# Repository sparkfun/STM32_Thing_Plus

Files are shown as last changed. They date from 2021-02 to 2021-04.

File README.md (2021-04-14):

SparkFun STM32 Thing Plus
========================================

SparkFun STM32 Thing Plus

[*SparkFun STM32 Thing Plus (17712)*](https://www.sparkfun.com/products/17712)

What incorporates a high-performance Arm® Cortex®-M4 32-bit RISC core, a full set of DSP instructions, memory protection unit (MPU), high-speed embedded memories, up to 4 Kbytes of backup SRAM, and an extensive range of enhanced I/Os and peripherals? The new [SparkFun STM32 Thing Plus](https://www.sparkfun.com/products/17712) has all this and more in the popular, Feather-compatible Thing Plus form factor. 

Repository Contents
-------------------

* **/Hardware** - Eagle design files (.brd, .sch)
* **/Production** - Production panel files (.brd)

Documentation
--------------
* **[Hookup Guide](https://learn.sparkfun.com/tutorials/stm32-thing-plus-hookup-guide)** - Basic hookup guide for the STM32 Thing Plus.
* **[SparkFun Graphical Datasheets](https://github.com/sparkfun/Graphical_Datasheets)** -Graphical Datasheets for various SparkFun products.

License Information
-------------------

This product is _**open source**_! 

Please review the LICENSE.md file for license information. 

If you have any questions or concerns on licensing, please contact technical support on our [SparkFun forums](https://forum.sparkfun.com/viewforum.php?f=152).

Distributed as-is; no warranty is given.

- Your friends at SparkFun.

_<COLLABORATION CREDIT>_

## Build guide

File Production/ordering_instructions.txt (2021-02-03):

panel size, 201x124mm
PCB thickness, 1.6mm
number of layers, 2
soldermask color, Red
silkscreen color, White
oz copper, 1oz
finish, HASL lead free
stencils, top+bottom
pcs per panel, 15
min trace width, 0.2000mm / 0.0079in
min drill size, 0.3048mm / 0.0120in

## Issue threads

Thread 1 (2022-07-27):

STM32F405 Express, PCB errors about SD card detection

dombru54, 2022-07-27:
Hello,

1) With your SparkFunThingPlus-STM32F405 card, the PB12 pin (cardDetect) is not connected to reader card pin 10.
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

2) There is a short circuit with the card reader double pin 10
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

Error in the card reader manufacturer's datasheet and red correction
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

Erase thermal-break, pin 10 will no longer be grounded
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

Thanks to make a revision of this board

dombru54, 2022-07-27:
Sorry, error tittle, it's ThingPlus, not Express

Thanks to modify tittle

dombru54, 2022-07-27:
Sorry,
The new schema corrected
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

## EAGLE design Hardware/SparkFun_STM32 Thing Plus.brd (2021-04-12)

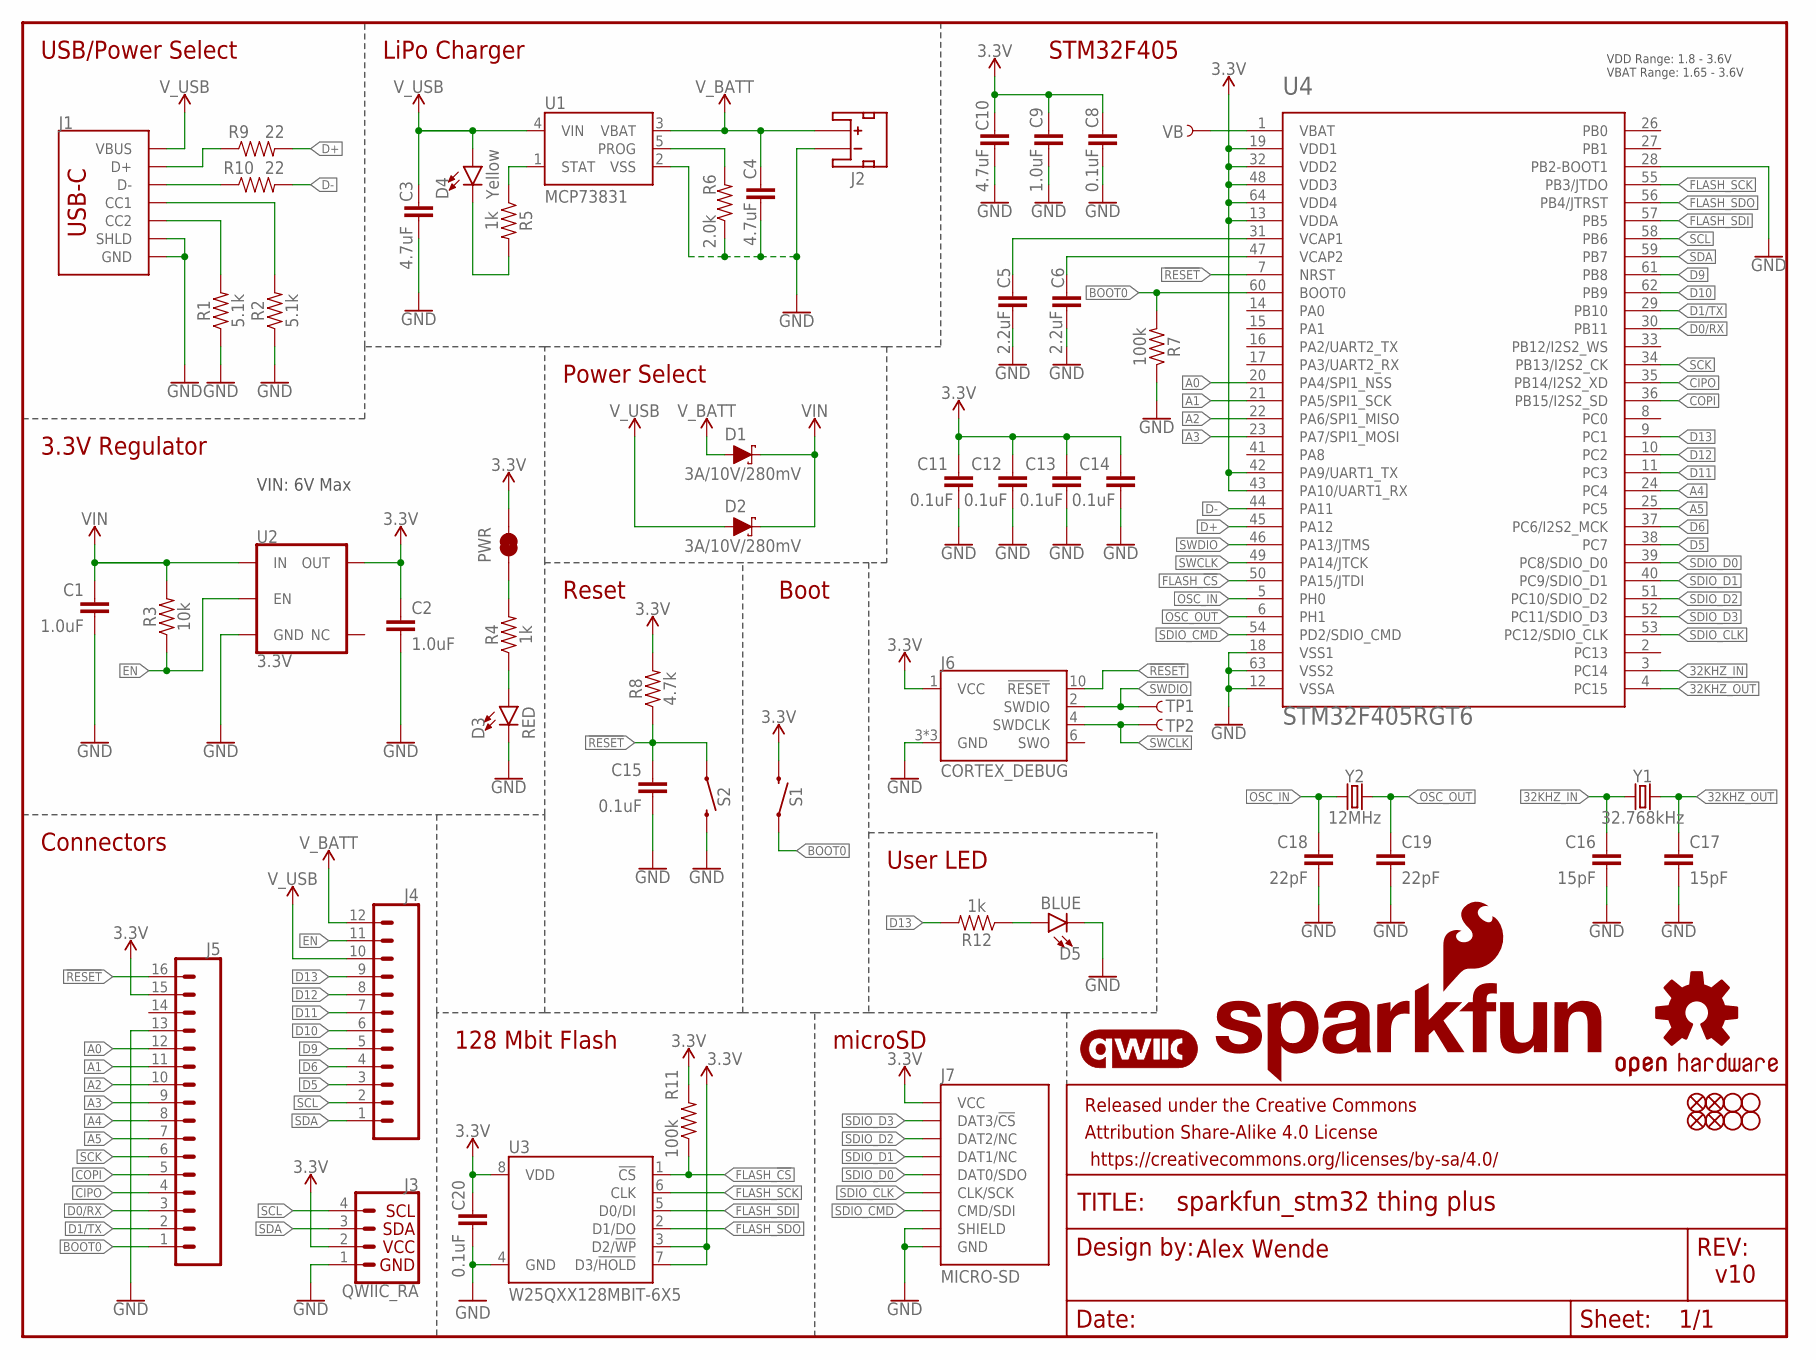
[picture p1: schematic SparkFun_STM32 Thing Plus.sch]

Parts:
C1, C2, C9: 1.0uF; 0402-TIGHT
C3, C4, C10: 4.7uF; 0402-TIGHT
C5, C6: 2.2uF; 0402-TIGHT
C8, C11, C12, C13, C14, C15, C20: 0.1uF; 0402-TIGHT
C16, C17: 15pF; 0402-TIGHT
C18, C19: 22pF; 0402-TIGHT
D1, D2: 3A/10V/280mV; SOD-323
D3: RED; LED-0603
D4: Yellow; LED-0603
D5: BLUE; LED-0603
FD1, FD2, FD3, FD4: FIDUCIALUFIDUCIAL; FIDUCIAL-MICRO
FRAME1: FRAME-LETTER; CREATIVE_COMMONS
H1, H2, H3, H4: STAND-OFFTIGHT; STAND-OFF-TIGHT
J1: USB_C_2-LAYER_PADS; USB-C-16P-2LAYER-PADS
J2: JST_2MM_MALE; JST-2-SMD
J3: QWIIC_RA; JST04_1MM_RA
J4: CONN_12SM_SQ_NO_SILK; 1X12_SM_SQ_NOSILK
J5: CONN_161X16_SM_SQ_NOSILK; 1X16_SM_SQ_NOSILK
J6: CORTEX_DEBUG; 2X5-PTH-1.27MM-NO_SILK
J7: MICRO-SD; MICRO-SD-SOCKET
LOGO1: QWIIC_LOGO_5MM; QWIIC_5MM
LOGO2: SFE_LOGO_NAME_FLAME.1_INCH; SFE_LOGO_NAME_FLAME_.1
LOGO3: OSHW-LOGOS; OSHW-LOGO-S
PWR: JUMPER-SMT_2_NC_TRACE_NO-SILK; SMT-JUMPER_2_NC_TRACE_NO-SILK
R1, R2: 5.1k; 0603
R3: 10k; 0603
R4, R5, R12: 1k; 0402-TIGHT
R6: 2.0k; 0603
R7, R11: 100k; 0402-TIGHT
R8: 4.7k; 0603
R9, R10: 22; 0603
S1, S2: MOMENTARY-SWITCH-SPST-SMD-4.6X2.8MM; TACTILE_SWITCH_SMD_4.6X2.8MM
TP1, TP2: TEST-POINT3; PAD.03X.03
U1: MCP73831; SOT23-5
U2: 3.3V; SOT23-5
U3: W25QXX128MBIT-6X5; WSON-8-6X5
U4: STM32F405RGT6; TQFP64
VB: TEST-POINT3; PAD.03X.03
Y1: 32.768kHz; CRYSTAL-SMD-3.2X1.5MM
Y2: 12MHz; CRYSTAL-SMD-5X3.2-4PAD

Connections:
3.3V: C2.1, C8.1, C9.1, C10.1, C11.1, C12.1, C13.1, C14.1, C20.1, J3.2, J5.15, J6.1 (VCC), J7.VCC, PWR.2, R8.2, R11.2, S1.3 (2), S1.4 (2), U2.5 (OUT), U3.3 (D2/!WP!), U3.7 (D3/!HOLD!), U3.8 (VDD), U4.13 (VDDA), U4.19 (VDD1), U4.32 (VDD2), U4.42 (PA9/UART1_TX), U4.43 (PA10/UART1_RX), U4.48 (VDD3), U4.64 (VDD4)
32KHZ_IN: C16.1, U4.3 (PC14), Y1.P$1 (1)
32KHZ_OUT: C17.1, U4.4 (PC15), Y1.P$2 (2)
!RESET: C15.1, J5.16, J6.10 (!RESET), R8.1, S2.1, S2.2 (1), U4.7 (NRST)
A0: J5.12, U4.20 (PA4/SPI1_NSS)
A1: J5.11, U4.21 (PA5/SPI1_SCK)
A2: J5.10, U4.22 (PA6/SPI1_MISO)
A3: J5.9, U4.23 (PA7/SPI1_MOSI)
A4: J5.8, U4.24 (PC4)
A5: J5.7, U4.25 (PC5)
BOOT0: J5.1, R7.2, S1.1, S1.2 (1), U4.60 (BOOT0)
CIPO: J5.4, U4.35 (PB14/I2S2_XD)
COPI: J5.5, U4.36 (PB15/I2S2_SD)
D0/RX: J5.3, U4.30 (PB11)
D1/TX: J5.2, U4.29 (PB10)
D5: J4.3, U4.38 (PC7)
D6: J4.4, U4.37 (PC6/I2S2_MCK)
D9: J4.5, U4.61 (PB8)
D10: J4.6, U4.62 (PB9)
D11: J4.7, U4.11 (PC3)
D12: J4.8, U4.10 (PC2)
D13: J4.9, R12.2, U4.9 (PC1)
D+: R9.2, U4.45 (PA12)
D-: R10.2, U4.44 (PA11)
EN: J4.11, R3.1, U2.3 (EN)
FLASH_!CS: R11.1, U3.1 (!CS!), U4.50 (PA15/JTDI)
FLASH_SCK: U3.6 (CLK), U4.55 (PB3/JTDO)
FLASH_SDI: U3.5 (D0/DI), U4.57 (PB5)
FLASH_SDO: U3.2 (D1/DO), U4.56 (PB4/JTRST)
GND: C1.2, C2.2, C3.2, C4.2, C5.2, C6.2, C8.2, C9.2, C10.2, C11.2, C12.2, C13.2, C14.2, C15.2, C16.2, C17.2, C18.2, C19.2, C20.2, D3.C, D5.C, J1.GND, J1.GND2 (GND), J1.SHLD1 (SHLD), J1.SHLD2 (SHLD), J1.SHLD3 (SHLD), J1.SHLD4 (SHLD), J2.1 (-), J3.1, J5.13, J6.3 (GND), J6.5 (GND), J6.9 (GND), J7.CD1 (SHIELD), J7.GND, J7.GND1 (GND), J7.GND3 (GND), R1.1, R2.1, R6.1, R7.1, S2.3 (2), S2.4 (2), U1.2 (VSS), U2.2 (GND), U3.4 (GND), U4.12 (VSSA), U4.18 (VSS1), U4.28 (PB2-BOOT1), U4.63 (VSS2)
unnamed: D5.A, R12.1
unnamed: PWR.1, R4.2
unnamed: J1.A6 (D+), J1.B6 (D+), R9.1
unnamed: J1.A7 (D-), J1.B7 (D-), R10.1
unnamed: D3.A, R4.1
unnamed: R6.2, U1.5 (PROG)
unnamed: J1.A5 (CC1), R2.2
unnamed: J1.B5 (CC2), R1.2
unnamed: D4.C, R5.2
unnamed: R5.1, U1.1 (STAT)
unnamed: C5.1, U4.31 (VCAP1)
unnamed: C6.1, U4.47 (VCAP2)
OSC_IN: C18.1, U4.5 (PH0), Y2.1
OSC_OUT: C19.1, U4.6 (PH1), Y2.3 (2)
SCK: J5.6, U4.34 (PB13/I2S2_CK)
SCL: J3.4, J4.2, U4.58 (PB6)
SDA: J3.3, J4.1, U4.59 (PB7)
SDIO_CLK: J7.SCLK (CLK/SCK), U4.53 (PC12/SDIO_CLK)
SDIO_CMD: J7.DI/CMD (CMD/SDI), U4.54 (PD2/SDIO_CMD)
SDIO_D0: J7.DO/DAT0 (DAT0/SDO), U4.39 (PC8/SDIO_D0)
SDIO_D1: J7.DAT1 (DAT1/NC), U4.40 (PC9/SDIO_D1)
SDIO_D2: J7.DAT2 (DAT2/NC), U4.51 (PC10/SDIO_D2)
SDIO_D3: J7.CS/DAT3 (DAT3/!CS!), U4.52 (PC11/SDIO_D3)
SWCLK: J6.4 (SWDCLK), TP2.P$1, U4.49 (PA14/JTCK)
SWDIO: J6.2 (SWDIO), TP1.P$1, U4.46 (PA13/JTMS)
VB: U4.1 (VBAT), VB.P$1
VIN: C1.1, D1.C, D2.C, R3.2, U2.1 (IN)
V_BATT: C4.1, D1.A, J2.2 (+), J4.12, U1.3 (VBAT)
V_USB: C3.1, D2.A, D4.A, J1.VBUS1 (VBUS), J1.VBUS2 (VBUS), J4.10, U1.4 (VIN)

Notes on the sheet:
v10
Alex Wende
3.3V Regulator
VIN: 6V Max
LiPo Charger
USB/Power Select
Power Select
Connectors
microSD
128 Mbit Flash
Reset
Boot
User LED
VDD Range: 1.8 - 3.6V VBAT Range: 1.65 - 3.6V
STM32F405

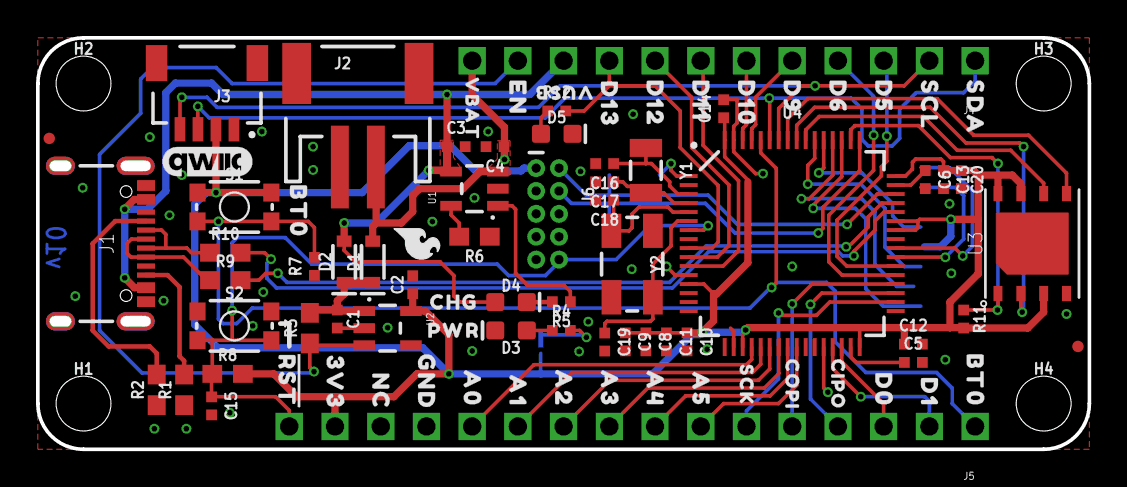
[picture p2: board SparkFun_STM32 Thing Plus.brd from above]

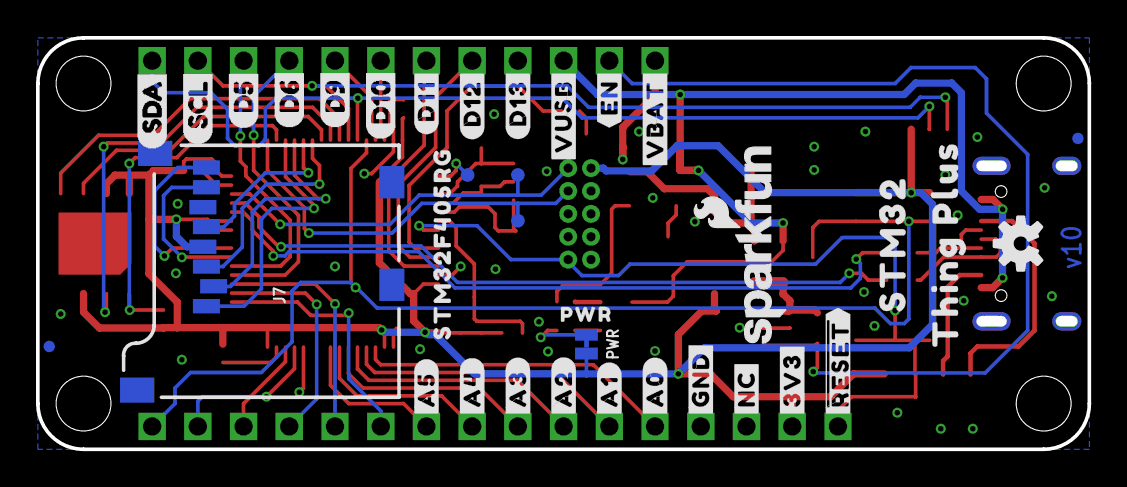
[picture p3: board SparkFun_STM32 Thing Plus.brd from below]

Board: 2 copper layers, 58.4 x 22.9 mm, 125 parts (35 on the bottom side), 59 nets.

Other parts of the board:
U$1: D53
U$2: #RST#0
U$3, U$49: BT00
U$4: D130
U$5, U$58: PWR0
U$6: CHG0
U$7: ##RESET##0
U$8: #3V3#0
U$9: #NC#0
U$10: #GND#0
U$11: #A0#0
U$12: #A1#0
U$13: #A2#0
U$14: #A3#0
U$15: #A4#0
U$16: #A5#0
U$23: D62
U$24: D91
U$25, U$55: D100
U$26: SCL4
U$27: SDA5
U$29: #D11#0
U$30: #D12#0
U$31: #D13#0
U$32: #VUSB#0
U$33: #EN#0
U$34: #VBAT#0
U$35: 3V30
U$36: NC0
U$37: GND0
U$38: A00
U$39: A10
U$40: A20
U$41: A30
U$42: A40
U$43: A50
U$44: SCK0
U$45: COPI0
U$46: CIPO0
U$47: D00
U$48: D10
U$50: VBAT_0
U$51: EN_0
U$52: D50
U$53: D60
U$54: D90
U$56: D110
U$57: D120
U$59: SCL_0
U$60: SDA_0
U$61: VUSB0
U$62: STM320
U$63: THING_PLUS0
U$64: STM32F405RG0
U$65: SFE_LOGO_FLAME_.1

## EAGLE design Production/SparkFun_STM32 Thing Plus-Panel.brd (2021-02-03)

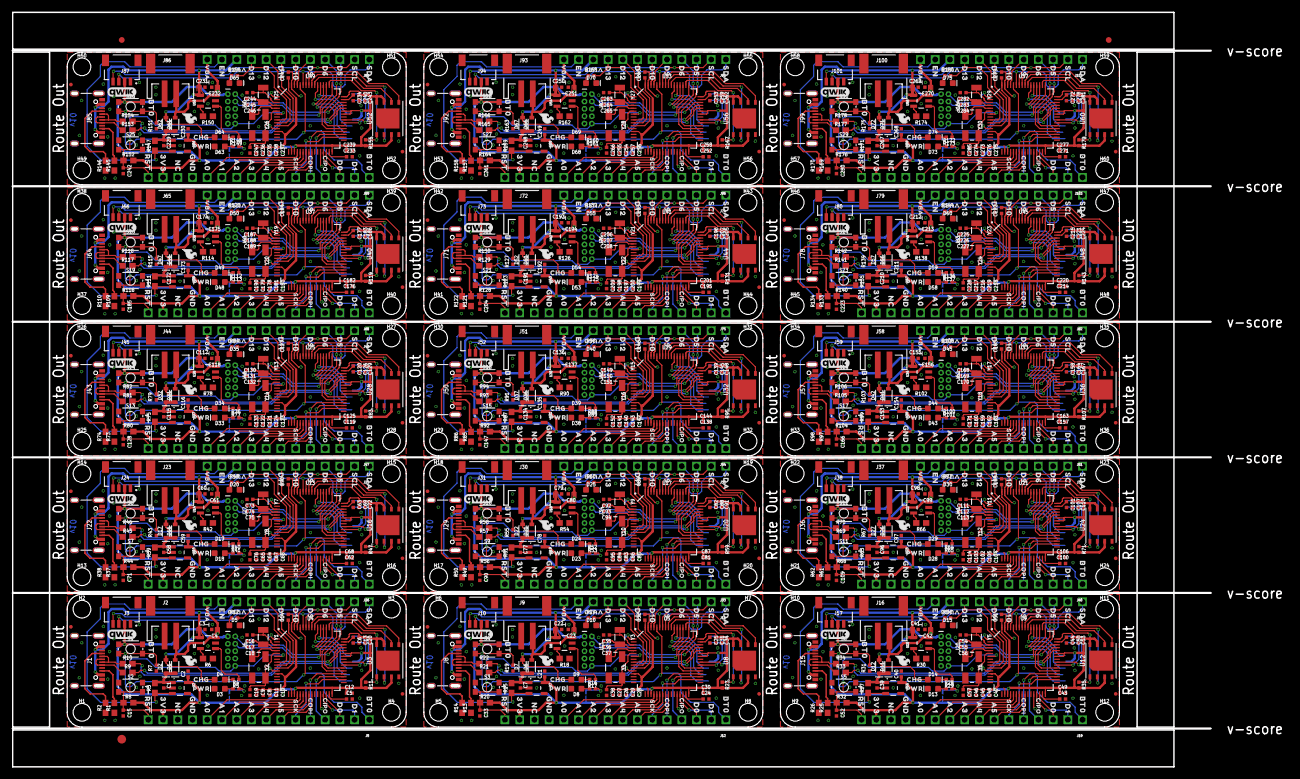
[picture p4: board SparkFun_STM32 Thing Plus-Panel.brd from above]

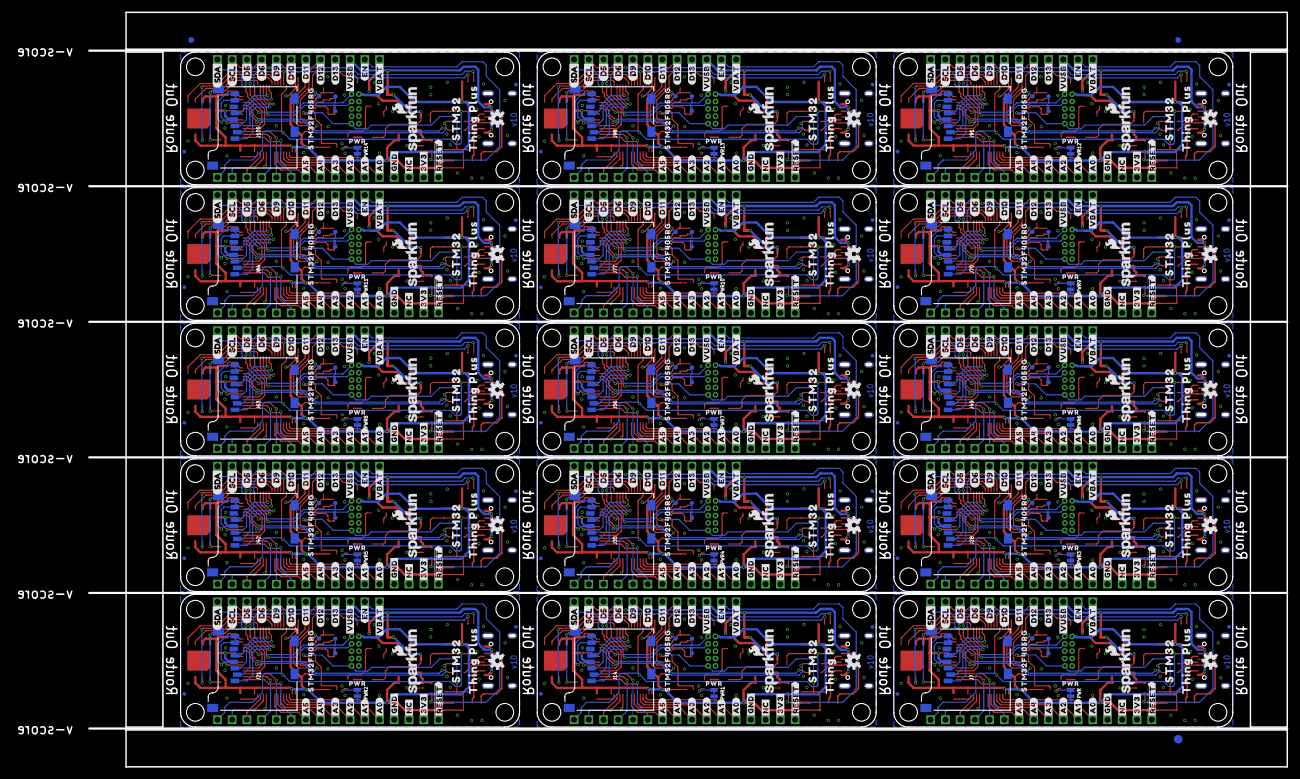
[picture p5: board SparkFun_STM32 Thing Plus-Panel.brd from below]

Board: 2 copper layers, 206.5 x 130.0 mm, 1866 parts (528 on the bottom side), 885 nets.

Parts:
C1, C2, C7, C9, C21, C27, C39, C40, C46, C58, C59, C65, C77, C78, C84, C96, C97, C103, C115, C116, C122, C134, C135, C141, C153, C154, C160, C172, C173, C179, C191, C192, C198, C210, C211, C217, C229, C230, C236, C248, C249, C255, C267, C268, C274: 1.0uF; 0402-TIGHT
C3, C4, C10, C22, C23, C28, C41, C42, C47, C60, C61, C66, C79, C80, C85, C98, C99, C104, C117, C118, C123, C136, C137, C142, C155, C156, C161, C174, C175, C180, C193, C194, C199, C212, C213, C218, C231, C232, C237, C250, C251, C256, C269, C270, C275: 4.7uF; 0402-TIGHT
C5, C6, C24, C25, C43, C44, C62, C63, C81, C82, C100, C101, C119, C120, C138, C139, C157, C158, C176, C177, C195, C196, C214, C215, C233, C234, C252, C253, C271, C272: 2.2uF; 0402-TIGHT
C8, C11, C12, C13, C14, C15, C20, C26, C29, C30, C31, C32, C33, C34, C45, C48, C49, C50, C51, C52, C53, C64, C67, C68, C69, C70, C71, C72, C83, C86, C87, C88, C89, C90, C91, C102, C105, C106, C107, C108, C109, C110, C121, C124, C125, C126, C127, C128, C129, C140, C143, C144, C145, C146, C147, C148, C159, C162, C163, C164, C165, C166, C167, C178, C181, C182, C183, C184, C185, C186, C197, C200, C201, C202, C203, C204, C205, C216, C219, C220, C221, C222, C223, C224, C235, C238, C239, C240, C241, C242, C243, C254, C257, C258, C259, C260, C261, C262, C273, C276, C277, C278, C279, C280, C281: 0.1uF; 0402-TIGHT
C16, C17, C35, C36, C54, C55, C73, C74, C92, C93, C111, C112, C130, C131, C149, C150, C168, C169, C187, C188, C206, C207, C225, C226, C244, C245, C263, C264, C282, C283: 15pF; 0402-TIGHT
C18, C19, C37, C38, C56, C57, C75, C76, C94, C95, C113, C114, C132, C133, C151, C152, C170, C171, C189, C190, C208, C209, C227, C228, C246, C247, C265, C266, C284, C285: 22pF; 0402-TIGHT
D1, D2, D6, D7, D11, D12, D16, D17, D21, D22, D26, D27, D31, D32, D36, D37, D41, D42, D46, D47, D51, D52, D56, D57, D61, D62, D66, D67, D71, D72: 3A/10V/280mV; SOD-323
D3, D8, D13, D18, D23, D28, D33, D38, D43, D48, D53, D58, D63, D68, D73: RED; LED-0603
D4, D9, D14, D19, D24, D29, D34, D39, D44, D49, D54, D59, D64, D69, D74: Yellow; LED-0603
D5, D10, D15, D20, D25, D30, D35, D40, D45, D50, D55, D60, D65, D70, D75: BLUE; LED-0603
E$1, E$2, E$3, E$4: FIDUCIAL-1X2
E$5, E$6: FIDUCIAL-1.5X3
FD1, FD2, FD3, FD4, FD5, FD6, FD7, FD8, FD9, FD10, FD11, FD12, FD13, FD14, FD15, FD16, FD17, FD18, FD19, FD20, FD21, FD22, FD23, FD24, FD25, FD26, FD27, FD28, FD29, FD30, FD31, FD32, FD33, FD34, FD35, FD36, FD37, FD38, FD39, FD40, FD41, FD42, FD43, FD44, FD45, FD46, FD47, FD48, FD49, FD50, FD51, FD52, FD53, FD54, FD55, FD56, FD57, FD58, FD59, FD60: FIDUCIALUFIDUCIAL; FIDUCIAL-MICRO
H1, H2, H3, H4, H5, H6, H7, H8, H9, H10, H11, H12, H13, H14, H15, H16, H17, H18, H19, H20, H21, H22, H23, H24, H25, H26, H27, H28, H29, H30, H31, H32, H33, H34, H35, H36, H37, H38, H39, H40, H41, H42, H43, H44, H45, H46, H47, H48, H49, H50, H51, H52, H53, H54, H55, H56, H57, H58, H59, H60: STAND-OFFTIGHT; STAND-OFF-TIGHT
J1, J8, J15, J22, J29, J36, J43, J50, J57, J64, J71, J78, J85, J92, J99: USB-C-16P-2LAYER-PADS
J2, J9, J16, J23, J30, J37, J44, J51, J58, J65, J72, J79, J86, J93, J100: JST-2-SMD
J3, J10, J17, J24, J31, J38, J45, J52, J59, J66, J73, J80, J87, J94, J101: QWIIC_RA; JST04_1MM_RA
J4, J11, J18, J25, J32, J39, J46, J53, J60, J67, J74, J81, J88, J95, J102: 1X12_SM_SQ_NOSILK
J5, J12, J19, J26, J33, J40, J47, J54, J61, J68, J75, J82, J89, J96, J103: 1X16_SM_SQ_NOSILK
J6, J13, J20, J27, J34, J41, J48, J55, J62, J69, J76, J83, J90, J97, J104: CORTEX_DEBUG; 2X5-PTH-1.27MM-NO_SILK
J7, J14, J21, J28, J35, J42, J49, J56, J63, J70, J77, J84, J91, J98, J105: MICRO-SD; MICRO-SD-SOCKET
LOGO1, LOGO4, LOGO7, LOGO10, LOGO13, LOGO16, LOGO19, LOGO22, LOGO25, LOGO28, LOGO31, LOGO34, LOGO37, LOGO40, LOGO43: QWIIC_LOGO_5MM; QWIIC_5MM
LOGO2, LOGO5, LOGO8, LOGO11, LOGO14, LOGO17, LOGO20, LOGO23, LOGO26, LOGO29, LOGO32, LOGO35, LOGO38, LOGO41, LOGO44: SFE_LOGO_NAME_FLAME.1_INCH; SFE_LOGO_NAME_FLAME_.1
LOGO3, LOGO6, LOGO9, LOGO12, LOGO15, LOGO18, LOGO21, LOGO24, LOGO27, LOGO30, LOGO33, LOGO36, LOGO39, LOGO42, LOGO45: OSHW-LOGOS; OSHW-LOGO-S
PWR, PWR1, PWR2, PWR3, PWR4, PWR5, PWR6, PWR7, PWR8, PWR9, PWR10, PWR11, PWR12, PWR13, PWR14: SMT-JUMPER_2_NC_TRACE_NO-SILK
R1, R2, R13, R14, R25, R26, R37, R38, R49, R50, R61, R62, R73, R74, R85, R86, R97, R98, R109, R110, R121, R122, R133, R134, R145, R146, R157, R158, R169, R170: 5.1k; 0603
R3, R15, R27, R39, R51, R63, R75, R87, R99, R111, R123, R135, R147, R159, R171: 10k; 0603
R4, R5, R12, R16, R17, R24, R28, R29, R36, R40, R41, R48, R52, R53, R60, R64, R65, R72, R76, R77, R84, R88, R89, R96, R100, R101, R108, R112, R113, R120, R124, R125, R132, R136, R137, R144, R148, R149, R156, R160, R161, R168, R172, R173, R180: 1k; 0402-TIGHT
R6, R18, R30, R42, R54, R66, R78, R90, R102, R114, R126, R138, R150, R162, R174: 2.0k; 0603
R7, R11, R19, R23, R31, R35, R43, R47, R55, R59, R67, R71, R79, R83, R91, R95, R103, R107, R115, R119, R127, R131, R139, R143, R151, R155, R163, R167, R175, R179: 100k; 0402-TIGHT
R8, R20, R32, R44, R56, R68, R80, R92, R104, R116, R128, R140, R152, R164, R176: 4.7k; 0603
R9, R10, R21, R22, R33, R34, R45, R46, R57, R58, R69, R70, R81, R82, R93, R94, R105, R106, R117, R118, R129, R130, R141, R142, R153, R154, R165, R166, R177, R178: 22; 0603
S1, S2, S3, S4, S5, S6, S7, S8, S9, S10, S11, S12, S13, S14, S15, S16, S17, S18, S19, S20, S21, S22, S23, S24, S25, S26, S27, S28, S29, S30: TACTILE_SWITCH_SMD_4.6X2.8MM
TP1, TP2, TP3, TP4, TP5, TP6, TP7, TP8, TP9, TP10, TP11, TP12, TP13, TP14, TP15, TP16, TP17, TP18, TP19, TP20, TP21, TP22, TP23, TP24, TP25, TP26, TP27, TP28, TP29, TP30: PAD.03X.03
U1, U6, U10, U14, U18, U22, U26, U30, U34, U38, U42, U46, U50, U54, U58: MCP73831; SOT23-5
U2, U7, U11, U15, U19, U23, U27, U31, U35, U39, U43, U47, U51, U55, U59: 3.3V; SOT23-5
U3, U8, U12, U16, U20, U24, U28, U32, U36, U40, U44, U48, U52, U56, U60: W25QXX128MBIT-6X5; WSON-8-6X5
U4, U5, U9, U13, U17, U21, U25, U29, U33, U37, U41, U45, U49, U53, U57: STM32F405RGT6; TQFP64
U$1, U$111, U$169, U$227, U$285, U$343, U$401, U$459, U$517, U$575, U$633, U$691, U$749, U$807, U$865: D53
U$2, U$17, U$117, U$175, U$233, U$291, U$349, U$407, U$465, U$523, U$581, U$639, U$697, U$755, U$813: #RST#0
U$3, U$49, U$90, U$97, U$148, U$155, U$206, U$213, U$264, U$271, U$322, U$329, U$380, U$387, U$438, U$445, U$496, U$503, U$554, U$561, U$612, U$619, U$670, U$677, U$728, U$735, U$786, U$793, U$844, U$851: BT00
U$4, U$18, U$118, U$176, U$234, U$292, U$350, U$408, U$466, U$524, U$582, U$640, U$698, U$756, U$814: D130
U$5, U$19, U$58, U$101, U$119, U$159, U$177, U$217, U$235, U$275, U$293, U$333, U$351, U$391, U$409, U$449, U$467, U$507, U$525, U$565, U$583, U$623, U$641, U$681, U$699, U$739, U$757, U$797, U$815, U$855: PWR0
U$6, U$20, U$120, U$178, U$236, U$294, U$352, U$410, U$468, U$526, U$584, U$642, U$700, U$758, U$816: CHG0
U$7, U$21, U$121, U$179, U$237, U$295, U$353, U$411, U$469, U$527, U$585, U$643, U$701, U$759, U$817: ##RESET##0
U$8, U$22, U$122, U$180, U$238, U$296, U$354, U$412, U$470, U$528, U$586, U$644, U$702, U$760, U$818: #3V3#0
U$9, U$28, U$123, U$181, U$239, U$297, U$355, U$413, U$471, U$529, U$587, U$645, U$703, U$761, U$819: #NC#0
U$10, U$66, U$124, U$182, U$240, U$298, U$356, U$414, U$472, U$530, U$588, U$646, U$704, U$762, U$820: #GND#0
U$11, U$67, U$125, U$183, U$241, U$299, U$357, U$415, U$473, U$531, U$589, U$647, U$705, U$763, U$821: #A0#0
U$12, U$68, U$126, U$184, U$242, U$300, U$358, U$416, U$474, U$532, U$590, U$648, U$706, U$764, U$822: #A1#0
U$13, U$69, U$127, U$185, U$243, U$301, U$359, U$417, U$475, U$533, U$591, U$649, U$707, U$765, U$823: #A2#0
U$14, U$70, U$128, U$186, U$244, U$302, U$360, U$418, U$476, U$534, U$592, U$650, U$708, U$766, U$824: #A3#0
U$15, U$71, U$129, U$187, U$245, U$303, U$361, U$419, U$477, U$535, U$593, U$651, U$709, U$767, U$825: #A4#0
U$16, U$72, U$130, U$188, U$246, U$304, U$362, U$420, U$478, U$536, U$594, U$652, U$710, U$768, U$826: #A5#0
U$23, U$112, U$170, U$228, U$286, U$344, U$402, U$460, U$518, U$576, U$634, U$692, U$750, U$808, U$866: D62
U$24, U$113, U$171, U$229, U$287, U$345, U$403, U$461, U$519, U$577, U$635, U$693, U$751, U$809, U$867: D91
U$25, U$55, U$94, U$114, U$152, U$172, U$210, U$230, U$268, U$288, U$326, U$346, U$384, U$404, U$442, U$462, U$500, U$520, U$558, U$578, U$616, U$636, U$674, U$694, U$732, U$752, U$790, U$810, U$848, U$868: D100
U$26, U$115, U$173, U$231, U$289, U$347, U$405, U$463, U$521, U$579, U$637, U$695, U$753, U$811, U$869: SCL4
U$27, U$116, U$174, U$232, U$290, U$348, U$406, U$464, U$522, U$580, U$638, U$696, U$754, U$812, U$870: SDA5
U$29, U$73, U$131, U$189, U$247, U$305, U$363, U$421, U$479, U$537, U$595, U$653, U$711, U$769, U$827: #D11#0
U$30, U$74, U$132, U$190, U$248, U$306, U$364, U$422, U$480, U$538, U$596, U$654, U$712, U$770, U$828: #D12#0
U$31, U$75, U$133, U$191, U$249, U$307, U$365, U$423, U$481, U$539, U$597, U$655, U$713, U$771, U$829: #D13#0
U$32, U$76, U$134, U$192, U$250, U$308, U$366, U$424, U$482, U$540, U$598, U$656, U$714, U$772, U$830: #VUSB#0
U$33, U$77, U$135, U$193, U$251, U$309, U$367, U$425, U$483, U$541, U$599, U$657, U$715, U$773, U$831: #EN#0
U$34, U$78, U$136, U$194, U$252, U$310, U$368, U$426, U$484, U$542, U$600, U$658, U$716, U$774, U$832: #VBAT#0
U$35, U$79, U$137, U$195, U$253, U$311, U$369, U$427, U$485, U$543, U$601, U$659, U$717, U$775, U$833: 3V30
U$36, U$80, U$138, U$196, U$254, U$312, U$370, U$428, U$486, U$544, U$602, U$660, U$718, U$776, U$834: NC0
U$37, U$81, U$139, U$197, U$255, U$313, U$371, U$429, U$487, U$545, U$603, U$661, U$719, U$777, U$835: GND0
U$38, U$82, U$140, U$198, U$256, U$314, U$372, U$430, U$488, U$546, U$604, U$662, U$720, U$778, U$836: A00
U$39, U$83, U$141, U$199, U$257, U$315, U$373, U$431, U$489, U$547, U$605, U$663, U$721, U$779, U$837: A10
U$40, U$84, U$142, U$200, U$258, U$316, U$374, U$432, U$490, U$548, U$606, U$664, U$722, U$780, U$838: A20
U$41, U$85, U$143, U$201, U$259, U$317, U$375, U$433, U$491, U$549, U$607, U$665, U$723, U$781, U$839: A30
U$42, U$86, U$144, U$202, U$260, U$318, U$376, U$434, U$492, U$550, U$608, U$666, U$724, U$782, U$840: A40
U$43, U$87, U$145, U$203, U$261, U$319, U$377, U$435, U$493, U$551, U$609, U$667, U$725, U$783, U$841: A50
U$44, U$98, U$156, U$214, U$272, U$330, U$388, U$446, U$504, U$562, U$620, U$678, U$736, U$794, U$852: SCK0
U$45, U$99, U$157, U$215, U$273, U$331, U$389, U$447, U$505, U$563, U$621, U$679, U$737, U$795, U$853: COPI0
U$46, U$100, U$158, U$216, U$274, U$332, U$390, U$448, U$506, U$564, U$622, U$680, U$738, U$796, U$854: CIPO0
U$47, U$88, U$146, U$204, U$262, U$320, U$378, U$436, U$494, U$552, U$610, U$668, U$726, U$784, U$842: D00
U$48, U$89, U$147, U$205, U$263, U$321, U$379, U$437, U$495, U$553, U$611, U$669, U$727, U$785, U$843: D10
U$50, U$104, U$162, U$220, U$278, U$336, U$394, U$452, U$510, U$568, U$626, U$684, U$742, U$800, U$858: VBAT_0
U$51, U$105, U$163, U$221, U$279, U$337, U$395, U$453, U$511, U$569, U$627, U$685, U$743, U$801, U$859: EN_0
U$52, U$91, U$149, U$207, U$265, U$323, U$381, U$439, U$497, U$555, U$613, U$671, U$729, U$787, U$845: D50
U$53, U$92, U$150, U$208, U$266, U$324, U$382, U$440, U$498, U$556, U$614, U$672, U$730, U$788, U$846: D60
U$54, U$93, U$151, U$209, U$267, U$325, U$383, U$441, U$499, U$557, U$615, U$673, U$731, U$789, U$847: D90
U$56, U$95, U$153, U$211, U$269, U$327, U$385, U$443, U$501, U$559, U$617, U$675, U$733, U$791, U$849: D110
U$57, U$96, U$154, U$212, U$270, U$328, U$386, U$444, U$502, U$560, U$618, U$676, U$734, U$792, U$850: D120
U$59, U$102, U$160, U$218, U$276, U$334, U$392, U$450, U$508, U$566, U$624, U$682, U$740, U$798, U$856: SCL_0
U$60, U$103, U$161, U$219, U$277, U$335, U$393, U$451, U$509, U$567, U$625, U$683, U$741, U$799, U$857: SDA_0
U$61, U$106, U$164, U$222, U$280, U$338, U$396, U$454, U$512, U$570, U$628, U$686, U$744, U$802, U$860: VUSB0
U$62, U$107, U$165, U$223, U$281, U$339, U$397, U$455, U$513, U$571, U$629, U$687, U$745, U$803, U$861: STM320
U$63, U$108, U$166, U$224, U$282, U$340, U$398, U$456, U$514, U$572, U$630, U$688, U$746, U$804, U$862: THING_PLUS0
U$64, U$109, U$167, U$225, U$283, U$341, U$399, U$457, U$515, U$573, U$631, U$689, U$747, U$805, U$863: STM32F405RG0
U$65, U$110, U$168, U$226, U$284, U$342, U$400, U$458, U$516, U$574, U$632, U$690, U$748, U$806, U$864: SFE_LOGO_FLAME_.1
VB, VB1, VB2, VB3, VB4, VB5, VB6, VB7, VB8, VB9, VB10, VB11, VB12, VB13, VB14: PAD.03X.03
Y1, Y3, Y5, Y7, Y9, Y11, Y13, Y15, Y17, Y19, Y21, Y23, Y25, Y27, Y29: 32.768kHz; CRYSTAL-SMD-3.2X1.5MM
Y2, Y4, Y6, Y8, Y10, Y12, Y14, Y16, Y18, Y20, Y22, Y24, Y26, Y28, Y30: 12MHz; CRYSTAL-SMD-5X3.2-4PAD

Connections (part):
3.3V: C2.1, C8.1, C9.1, C10.1, C11.1, C12.1, C13.1, C14.1, C20.1, J3.2, J5.15, J6.1, J7.VCC, PWR.2, R8.2, R11.2, S1.3, S1.4, U2.5, U3.3, U3.7, U3.8, U4.13, U4.19, U4.32, U4.42, U4.43, U4.48, U4.64
3.3V1: C21.1, C26.1, C27.1, C28.1, C29.1, C30.1, C31.1, C32.1, C34.1, J10.2, J12.15, J13.1, J14.VCC, PWR1.2, R20.2, R23.2, S4.3, S4.4, U5.13, U5.19, U5.32, U5.42, U5.43, U5.48, U5.64, U7.5, U8.3, U8.7, U8.8
3.3V2: C40.1, C45.1, C46.1, C47.1, C48.1, C49.1, C50.1, C51.1, C53.1, J17.2, J19.15, J20.1, J21.VCC, PWR2.2, R32.2, R35.2, S6.3, S6.4, U9.13, U9.19, U9.32, U9.42, U9.43, U9.48, U9.64, U11.5, U12.3, U12.7, U12.8
3.3V3: C59.1, C64.1, C65.1, C66.1, C67.1, C68.1, C69.1, C70.1, C72.1, J24.2, J26.15, J27.1, J28.VCC, PWR3.2, R44.2, R47.2, S8.3, S8.4, U13.13, U13.19, U13.32, U13.42, U13.43, U13.48, U13.64, U15.5, U16.3, U16.7, U16.8
3.3V4: C78.1, C83.1, C84.1, C85.1, C86.1, C87.1, C88.1, C89.1, C91.1, J31.2, J33.15, J34.1, J35.VCC, PWR4.2, R56.2, R59.2, S10.3, S10.4, U17.13, U17.19, U17.32, U17.42, U17.43, U17.48, U17.64, U19.5, U20.3, U20.7, U20.8
3.3V5: C97.1, C102.1, C103.1, C104.1, C105.1, C106.1, C107.1, C108.1, C110.1, J38.2, J40.15, J41.1, J42.VCC, PWR5.2, R68.2, R71.2, S12.3, S12.4, U21.13, U21.19, U21.32, U21.42, U21.43, U21.48, U21.64, U23.5, U24.3, U24.7, U24.8
3.3V6: C116.1, C121.1, C122.1, C123.1, C124.1, C125.1, C126.1, C127.1, C129.1, J45.2, J47.15, J48.1, J49.VCC, PWR6.2, R80.2, R83.2, S14.3, S14.4, U25.13, U25.19, U25.32, U25.42, U25.43, U25.48, U25.64, U27.5, U28.3, U28.7, U28.8
3.3V7: C135.1, C140.1, C141.1, C142.1, C143.1, C144.1, C145.1, C146.1, C148.1, J52.2, J54.15, J55.1, J56.VCC, PWR7.2, R92.2, R95.2, S16.3, S16.4, U29.13, U29.19, U29.32, U29.42, U29.43, U29.48, U29.64, U31.5, U32.3, U32.7, U32.8
3.3V8: C154.1, C159.1, C160.1, C161.1, C162.1, C163.1, C164.1, C165.1, C167.1, J59.2, J61.15, J62.1, J63.VCC, PWR8.2, R104.2, R107.2, S18.3, S18.4, U33.13, U33.19, U33.32, U33.42, U33.43, U33.48, U33.64, U35.5, U36.3, U36.7, U36.8
3.3V9: C173.1, C178.1, C179.1, C180.1, C181.1, C182.1, C183.1, C184.1, C186.1, J66.2, J68.15, J69.1, J70.VCC, PWR9.2, R116.2, R119.2, S20.3, S20.4, U37.13, U37.19, U37.32, U37.42, U37.43, U37.48, U37.64, U39.5, U40.3, U40.7, U40.8
3.3V10: C192.1, C197.1, C198.1, C199.1, C200.1, C201.1, C202.1, C203.1, C205.1, J73.2, J75.15, J76.1, J77.VCC, PWR10.2, R128.2, R131.2, S22.3, S22.4, U41.13, U41.19, U41.32, U41.42, U41.43, U41.48, U41.64, U43.5, U44.3, U44.7, U44.8
3.3V11: C211.1, C216.1, C217.1, C218.1, C219.1, C220.1, C221.1, C222.1, C224.1, J80.2, J82.15, J83.1, J84.VCC, PWR11.2, R140.2, R143.2, S24.3, S24.4, U45.13, U45.19, U45.32, U45.42, U45.43, U45.48, U45.64, U47.5, U48.3, U48.7, U48.8
3.3V12: C230.1, C235.1, C236.1, C237.1, C238.1, C239.1, C240.1, C241.1, C243.1, J87.2, J89.15, J90.1, J91.VCC, PWR12.2, R152.2, R155.2, S26.3, S26.4, U49.13, U49.19, U49.32, U49.42, U49.43, U49.48, U49.64, U51.5, U52.3, U52.7, U52.8
3.3V13: C249.1, C254.1, C255.1, C256.1, C257.1, C258.1, C259.1, C260.1, C262.1, J94.2, J96.15, J97.1, J98.VCC, PWR13.2, R164.2, R167.2, S28.3, S28.4, U53.13, U53.19, U53.32, U53.42, U53.43, U53.48, U53.64, U55.5, U56.3, U56.7, U56.8
3.3V14: C268.1, C273.1, C274.1, C275.1, C276.1, C277.1, C278.1, C279.1, C281.1, J101.2, J103.15, J104.1, J105.VCC, PWR14.2, R176.2, R179.2, S30.3, S30.4, U57.13, U57.19, U57.32, U57.42, U57.43, U57.48, U57.64, U59.5, U60.3, U60.7, U60.8
32KHZ_IN: C16.1, U4.3, Y1.P$1
32KHZ_IN1: C35.1, U5.3, Y3.P$1
32KHZ_IN2: C54.1, U9.3, Y5.P$1
32KHZ_IN3: C73.1, U13.3, Y7.P$1
32KHZ_IN4: C92.1, U17.3, Y9.P$1
32KHZ_IN5: C111.1, U21.3, Y11.P$1
32KHZ_IN6: C130.1, U25.3, Y13.P$1
32KHZ_IN7: C149.1, U29.3, Y15.P$1
32KHZ_IN8: C168.1, U33.3, Y17.P$1
32KHZ_IN9: C187.1, U37.3, Y19.P$1
32KHZ_IN10: C206.1, U41.3, Y21.P$1
32KHZ_IN11: C225.1, U45.3, Y23.P$1
32KHZ_IN12: C244.1, U49.3, Y25.P$1
32KHZ_IN13: C263.1, U53.3, Y27.P$1
32KHZ_IN14: C282.1, U57.3, Y29.P$1
32KHZ_OUT: C17.1, U4.4, Y1.P$2
32KHZ_OUT1: C36.1, U5.4, Y3.P$2
32KHZ_OUT2: C55.1, U9.4, Y5.P$2
32KHZ_OUT3: C74.1, U13.4, Y7.P$2
32KHZ_OUT4: C93.1, U17.4, Y9.P$2
32KHZ_OUT5: C112.1, U21.4, Y11.P$2
32KHZ_OUT6: C131.1, U25.4, Y13.P$2
32KHZ_OUT7: C150.1, U29.4, Y15.P$2
32KHZ_OUT8: C169.1, U33.4, Y17.P$2
32KHZ_OUT9: C188.1, U37.4, Y19.P$2
32KHZ_OUT10: C207.1, U41.4, Y21.P$2
32KHZ_OUT11: C226.1, U45.4, Y23.P$2
32KHZ_OUT12: C245.1, U49.4, Y25.P$2
32KHZ_OUT13: C264.1, U53.4, Y27.P$2
32KHZ_OUT14: C283.1, U57.4, Y29.P$2
!RESET: C15.1, J5.16, J6.10, R8.1, S2.1, S2.2, U4.7
!RESET1: C33.1, J12.16, J13.10, R20.1, S3.1, S3.2, U5.7
!RESET2: C52.1, J19.16, J20.10, R32.1, S5.1, S5.2, U9.7
!RESET3: C71.1, J26.16, J27.10, R44.1, S7.1, S7.2, U13.7
!RESET4: C90.1, J33.16, J34.10, R56.1, S9.1, S9.2, U17.7
!RESET5: C109.1, J40.16, J41.10, R68.1, S11.1, S11.2, U21.7
!RESET6: C128.1, J47.16, J48.10, R80.1, S13.1, S13.2, U25.7
!RESET7: C147.1, J54.16, J55.10, R92.1, S15.1, S15.2, U29.7
!RESET8: C166.1, J61.16, J62.10, R104.1, S17.1, S17.2, U33.7
!RESET9: C185.1, J68.16, J69.10, R116.1, S19.1, S19.2, U37.7
!RESET10: C204.1, J75.16, J76.10, R128.1, S21.1, S21.2, U41.7
!RESET11: C223.1, J82.16, J83.10, R140.1, S23.1, S23.2, U45.7
!RESET12: C242.1, J89.16, J90.10, R152.1, S25.1, S25.2, U49.7
!RESET13: C261.1, J96.16, J97.10, R164.1, S27.1, S27.2, U53.7
!RESET14: C280.1, J103.16, J104.10, R176.1, S29.1, S29.2, U57.7
A0: J5.12, U4.20
A1: J5.11, U4.21
A2: J5.10, U4.22
A3: J5.9, U4.23
A4: J5.8, U4.24
A5: J5.7, U4.25
A6: J12.12, U5.20
A7: J12.11, U5.21
A8: J12.10, U5.22
A9: J12.9, U5.23
A10: J12.8, U5.24
A11: J12.7, U5.25
A12: J19.12, U9.20
A13: J19.11, U9.21
A14: J19.10, U9.22
A15: J19.9, U9.23
A16: J19.8, U9.24
A17: J19.7, U9.25
A18: J26.12, U13.20
A19: J26.11, U13.21
A20: J26.10, U13.22
A21: J26.9, U13.23
A22: J26.8, U13.24
A23: J26.7, U13.25
A24: J33.12, U17.20
A25: J33.11, U17.21
A26: J33.10, U17.22
A27: J33.9, U17.23
A28: J33.8, U17.24
A29: J33.7, U17.25
A30: J40.12, U21.20
A31: J40.11, U21.21
A32: J40.10, U21.22
A33: J40.9, U21.23
A34: J40.8, U21.24
A35: J40.7, U21.25
A36: J47.12, U25.20
A37: J47.11, U25.21
A38: J47.10, U25.22
A39: J47.9, U25.23
A40: J47.8, U25.24
A41: J47.7, U25.25
A42: J54.12, U29.20
A43: J54.11, U29.21
A44: J54.10, U29.22
A45: J54.9, U29.23
A46: J54.8, U29.24
A47: J54.7, U29.25
A48: J61.12, U33.20
A49: J61.11, U33.21
A50: J61.10, U33.22
A51: J61.9, U33.23
A52: J61.8, U33.24
A53: J61.7, U33.25
A54: J68.12, U37.20
A55: J68.11, U37.21
A56: J68.10, U37.22
A57: J68.9, U37.23
A58: J68.8, U37.24
A59: J68.7, U37.25
A60: J75.12, U41.20
A61: J75.11, U41.21
A62: J75.10, U41.22
A63: J75.9, U41.23
A64: J75.8, U41.24
A65: J75.7, U41.25
A66: J82.12, U45.20
A67: J82.11, U45.21
A68: J82.10, U45.22
A69: J82.9, U45.23
A70: J82.8, U45.24
A71: J82.7, U45.25
A72: J89.12, U49.20
A73: J89.11, U49.21
A74: J89.10, U49.22
A75: J89.9, U49.23
A76: J89.8, U49.24
A77: J89.7, U49.25
A78: J96.12, U53.20
A79: J96.11, U53.21
A80: J96.10, U53.22
A81: J96.9, U53.23
A82: J96.8, U53.24
A83: J96.7, U53.25
A84: J103.12, U57.20
A85: J103.11, U57.21
A86: J103.10, U57.22
A87: J103.9, U57.23
A88: J103.8, U57.24
A89: J103.7, U57.25
BOOT0: J5.1, R7.2, S1.1, S1.2, U4.60
BOOT1: J12.1, R19.2, S4.1, S4.2, U5.60
BOOT2: J19.1, R31.2, S6.1, S6.2, U9.60
BOOT3: J26.1, R43.2, S8.1, S8.2, U13.60
BOOT4: J33.1, R55.2, S10.1, S10.2, U17.60
BOOT5: J40.1, R67.2, S12.1, S12.2, U21.60
BOOT6: J47.1, R79.2, S14.1, S14.2, U25.60
BOOT7: J54.1, R91.2, S16.1, S16.2, U29.60
BOOT8: J61.1, R103.2, S18.1, S18.2, U33.60
BOOT9: J68.1, R115.2, S20.1, S20.2, U37.60
BOOT10: J75.1, R127.2, S22.1, S22.2, U41.60
BOOT11: J82.1, R139.2, S24.1, S24.2, U45.60
BOOT12: J89.1, R151.2, S26.1, S26.2, U49.60
BOOT13: J96.1, R163.2, S28.1, S28.2, U53.60
BOOT14: J103.1, R175.2, S30.1, S30.2, U57.60
CIPO: J5.4, U4.35
CIPO1: J12.4, U5.35
CIPO2: J19.4, U9.35
CIPO3: J26.4, U13.35
CIPO4: J33.4, U17.35
CIPO5: J40.4, U21.35
CIPO6: J47.4, U25.35
CIPO7: J54.4, U29.35
CIPO8: J61.4, U33.35
CIPO9: J68.4, U37.35
CIPO10: J75.4, U41.35
CIPO11: J82.4, U45.35
CIPO12: J89.4, U49.35
CIPO13: J96.4, U53.35
CIPO14: J103.4, U57.35
COPI: J5.5, U4.36
COPI1: J12.5, U5.36
COPI2: J19.5, U9.36
COPI3: J26.5, U13.36
COPI4: J33.5, U17.36
COPI5: J40.5, U21.36
COPI6: J47.5, U25.36
COPI7: J54.5, U29.36
COPI8: J61.5, U33.36
COPI9: J68.5, U37.36
COPI10: J75.5, U41.36
COPI11: J82.5, U45.36
COPI12: J89.5, U49.36
COPI13: J96.5, U53.36
COPI14: J103.5, U57.36
D0/RX: J5.3, U4.30
D0/RX1: J12.3, U5.30
D0/RX2: J19.3, U9.30
D0/RX3: J26.3, U13.30
D0/RX4: J33.3, U17.30
D0/RX5: J40.3, U21.30
D0/RX6: J47.3, U25.30
D0/RX7: J54.3, U29.30
D0/RX8: J61.3, U33.30
D0/RX9: J68.3, U37.30
D0/RX10: J75.3, U41.30
D0/RX11: J82.3, U45.30
D0/RX12: J89.3, U49.30
D0/RX13: J96.3, U53.30
D0/RX14: J103.3, U57.30
D1: J11.9, R24.2, U5.9
D1/TX: J5.2, U4.29
D1/TX1: J12.2, U5.29
D1/TX2: J19.2, U9.29
D1/TX3: J26.2, U13.29
D1/TX4: J33.2, U17.29
D1/TX5: J40.2, U21.29
D1/TX6: J47.2, U25.29
D1/TX7: J54.2, U29.29
D1/TX8: J61.2, U33.29
D1/TX9: J68.2, U37.29
D1/TX10: J75.2, U41.29
D1/TX11: J82.2, U45.29
D1/TX12: J89.2, U49.29
D1/TX13: J96.2, U53.29
D1/TX14: J103.2, U57.29
D2: J11.8, U5.10
D3: J11.7, U5.11
D4: J11.6, U5.62
D5: J4.3, U4.38
D6: J4.4, U4.37
D7: J11.5, U5.61
D8: J11.4, U5.37
D9: J4.5, U4.61
D10: J4.6, U4.62
D11: J4.7, U4.11
D12: J4.8, U4.10
D13: J4.9, R12.2, U4.9
D14: J11.3, U5.38
D15: J18.9, R36.2, U9.9
D16: J18.8, U9.10
D17: J18.7, U9.11
D18: J18.6, U9.62
D19: J18.5, U9.61
D20: J18.4, U9.37
D21: J18.3, U9.38
D22: J25.9, R48.2, U13.9
D23: J25.8, U13.10
D24: J25.7, U13.11
D25: J25.6, U13.62
D26: J25.5, U13.61
D27: J25.4, U13.37
D28: J25.3, U13.38
D29: J32.9, R60.2, U17.9
D30: J32.8, U17.10
D31: J32.7, U17.11
D32: J32.6, U17.62
D33: J32.5, U17.61
D34: J32.4, U17.37
D35: J32.3, U17.38
D36: J39.9, R72.2, U21.9
D37: J39.8, U21.10
D38: J39.7, U21.11
D39: J39.6, U21.62
D40: J39.5, U21.61
D41: J39.4, U21.37
D42: J39.3, U21.38
D43: J46.9, R84.2, U25.9
D44: J46.8, U25.10
D45: J46.7, U25.11
D46: J46.6, U25.62
D47: J46.5, U25.61
D48: J46.4, U25.37
D49: J46.3, U25.38
D50: J53.9, R96.2, U29.9
D51: J53.8, U29.10
D52: J53.7, U29.11
D53: J53.6, U29.62
D54: J53.5, U29.61
D55: J53.4, U29.37
D56: J53.3, U29.38
D57: J60.9, R108.2, U33.9
D58: J60.8, U33.10
D59: J60.7, U33.11
D60: J60.6, U33.62
D61: J60.5, U33.61
D62: J60.4, U33.37
D63: J60.3, U33.38
D64: J67.9, R120.2, U37.9
D65: J67.8, U37.10
D66: J67.7, U37.11
D67: J67.6, U37.62
D68: J67.5, U37.61
D69: J67.4, U37.37
D70: J67.3, U37.38
D71: J74.9, R132.2, U41.9
D72: J74.8, U41.10
D73: J74.7, U41.11
D74: J74.6, U41.62
D75: J74.5, U41.61
D76: J74.4, U41.37
D77: J74.3, U41.38
D78: J81.9, R144.2, U45.9
D79: J81.8, U45.10
D80: J81.7, U45.11
D81: J81.6, U45.62
D82: J81.5, U45.61
D83: J81.4, U45.37
D84: J81.3, U45.38
D85: J88.9, R156.2, U49.9
D86: J88.8, U49.10
D87: J88.7, U49.11
D88: J88.6, U49.62
D89: J88.5, U49.61
D90: J88.4, U49.37
D91: J88.3, U49.38
D92: J95.9, R168.2, U53.9
D93: J95.8, U53.10
D94: J95.7, U53.11
D95: J95.6, U53.62
D96: J95.5, U53.61
D97: J95.4, U53.37
D98: J95.3, U53.38
D99: J102.9, R180.2, U57.9
D100: J102.8, U57.10
D101: J102.7, U57.11
D102: J102.6, U57.62
D103: J102.5, U57.61
D104: J102.4, U57.37
D105: J102.3, U57.38
D+: R9.2, U4.45
D+1: R21.2, U5.45
D+2: R33.2, U9.45
D+3: R45.2, U13.45
D+4: R57.2, U17.45
D+5: R69.2, U21.45
D+6: R81.2, U25.45
D+7: R93.2, U29.45
D+8: R105.2, U33.45
D+9: R117.2, U37.45
D+10: R129.2, U41.45
D+11: R141.2, U45.45
D+12: R153.2, U49.45
D+13: R165.2, U53.45
D+14: R177.2, U57.45
D-: R10.2, U4.44
D-1: R22.2, U5.44
D-2: R34.2, U9.44
D-3: R46.2, U13.44
D-4: R58.2, U17.44
D-5: R70.2, U21.44
D-6: R82.2, U25.44
D-7: R94.2, U29.44
D-8: R106.2, U33.44
D-9: R118.2, U37.44
D-10: R130.2, U41.44
D-11: R142.2, U45.44
D-12: R154.2, U49.44
D-13: R166.2, U53.44
D-14: R178.2, U57.44
EN: J4.11, R3.1, U2.3
EN1: J11.11, R15.1, U7.3
EN2: J18.11, R27.1, U11.3
EN3: J25.11, R39.1, U15.3
EN4: J32.11, R51.1, U19.3
EN5: J39.11, R63.1, U23.3
EN6: J46.11, R75.1, U27.3
EN7: J53.11, R87.1, U31.3
EN8: J60.11, R99.1, U35.3
EN9: J67.11, R111.1, U39.3
EN10: J74.11, R123.1, U43.3
EN11: J81.11, R135.1, U47.3
EN12: J88.11, R147.1, U51.3
EN13: J95.11, R159.1, U55.3
EN14: J102.11, R171.1, U59.3
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

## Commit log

2020-12-07 Updated V01
    [SparkFun_STM32 Thing Plus.brd, SparkFun_STM32 Thing Plus.sch]
2021-01-28 Updated version number to V10
    [SparkFun_STM32 Thing Plus.brd, SparkFun_STM32 Thing Plus.sch]
2021-02-01 V10 design review changes
    Replaced V_BAT pin connection on STM32 to test point
    Moved microSD connector to center card on PCB instead of footprint
    Removed overlapping labels on bottom
    [SparkFun_STM32 Thing Plus.brd, SparkFun_STM32 Thing Plus.sch]
2021-02-02 Double-check changes
    Schematic
    - Added VDD range
    - Added RTC Battery range
    Board
    - Updated labels
    [SparkFun_STM32 Thing Plus.brd, SparkFun_STM32 Thing Plus.sch]
2021-02-02 added production panel
    [SparkFun_STM32 Thing Plus-Panel.GBL, SparkFun_STM32 Thing Plus-Panel.GBO, SparkFun_STM32 Thing Plus-Panel.GBP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]
2021-02-03 Updated Panel
    [SparkFun_STM32 Thing Plus-Panel.GBL, SparkFun_STM32 Thing Plus-Panel.GBO, SparkFun_STM32 Thing Plus-Panel.GBP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]
2021-03-29 BOM update
    Replaced 22 ohm resistors with 0 ohm
    Replaced old momentary switches to taller momentary switches
    [SparkFun_STM32 Thing Plus.brd, SparkFun_STM32 Thing Plus.sch]
2021-04-12 Updated USB Load Resistors
    Switch 0 ohm resistors back to 22 ohm
    [SparkFun_STM32 Thing Plus.brd, SparkFun_STM32 Thing Plus.sch]

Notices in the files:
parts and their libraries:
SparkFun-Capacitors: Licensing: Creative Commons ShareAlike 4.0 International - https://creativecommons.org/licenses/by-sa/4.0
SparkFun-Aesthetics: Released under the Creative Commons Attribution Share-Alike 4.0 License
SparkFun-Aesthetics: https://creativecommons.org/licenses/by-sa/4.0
